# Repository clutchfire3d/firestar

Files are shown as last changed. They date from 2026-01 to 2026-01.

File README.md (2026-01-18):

> [!IMPORTANT]
> **Official STL Files:** The 3D models for the Firestar platform will be available soon on the official **Polarstar Airsoft** website. Stay tuned to our [Discord community](https://discord.gg/8hraAGcFYY) for the official release announcement!

---

# Firestar – Assembly & Printing Manual 🚀
**Created by:** [@ClutchFire3D](https://www.instagram.com/clutchfire3d/)

[**🌐 View Official Website**](https://clutchfire3d.github.io/firestar/)

---

## ⚖️ License & Terms of Use
This project is licensed under **CC BY-NC-ND 4.0**. 
**Commercial use, redistribution, or sale of STL files and printed parts is strictly prohibited.**

---

## 📌 Table of Contents
* [1. Meet Firestar](#1-meet-firestar)
* [2. Recommended Print Settings](#recommended-print-settings)
* [3. Support the Mission](#support-the-mission-keep-the-fire-burning)
* [Step 1: Lower Receiver Preparation](#step-1-lower-receiver-preparation)
* [Step 2: Upper Receiver & Handguard](#step-2-upper-receiver--handguard)
* [Step 3: Trigger Housing & HPA](#step-3-trigger-housing--hpa)
* [Step 4: Stock Adapter](#step-4-stock-adapter)
* [Step 5: Final System Assembly](#step-5-final-system-assembly)
* [Step 6: Stock](#step-6-stock)

---

## 1. Meet Firestar
**Forget Gearboxes. Embrace Innovation.**

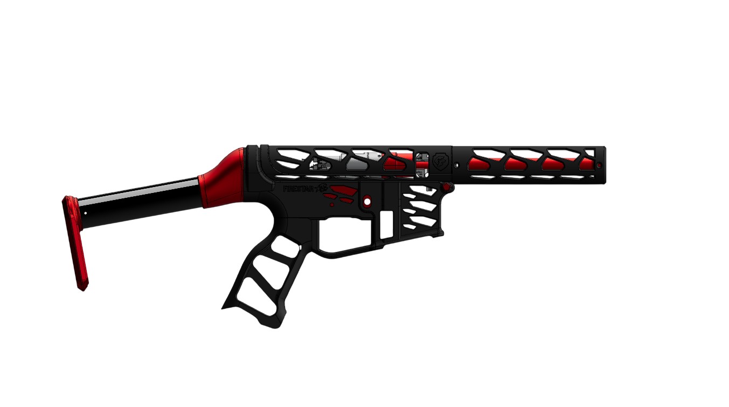
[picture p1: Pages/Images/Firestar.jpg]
Firestar


The Firestar was developed by **ClutchFire3D** leveraging **PolarStar Airsoft** technology. Designed from the ground up to extract maximum performance from the **F2™ and Jack™ HPA engines**, this platform eliminates the limitations of adapted AEG bodies.

---

## 🛠 Recommended Print Settings

To ensure the structural integrity of your Firestar, follow these guidelines:

| Parameter | Recommended Setting |
| :--- | :--- |
| **Material** | **ASA or ABS** (Required for impact resistance and durability) |
| **Wall Line Count** | **4 layers** (Crucial for thread and insert strength) |
| **Infill Density** | **50% or higher** |
| **Support** | Required (Tree supports recommended for cleaner surfaces) |
| **Layer Height** | 0.12mm |

> **⚠️ Warning:** Do not use standard PLA for structural parts, as it may become brittle or warp under heat and mechanical stress.

---

## ❤️ Support the Mission (Keep the Fire Burning)
The **Firestar** is an open-source project. If you find this project valuable, please consider supporting our work.



---

# Step 1: Lower Receiver Preparation

### **Trigger**
Install the trigger blade. Note the specific slot to prevent the selector from over-rotating. Secure with an M3 screw.
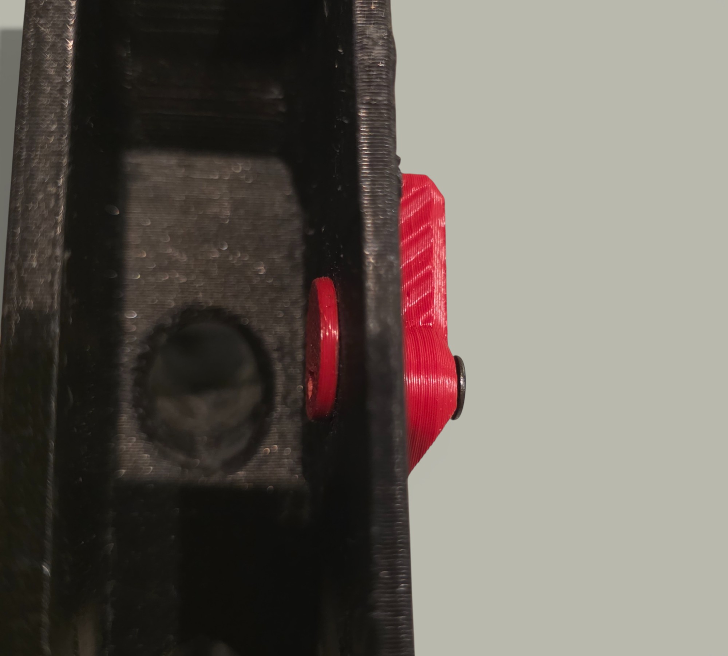
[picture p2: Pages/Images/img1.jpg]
Trigger Install


### **Grip Inserts**
Using a soldering iron, install the M3 brass inserts into the Pistol Grip mounting holes.
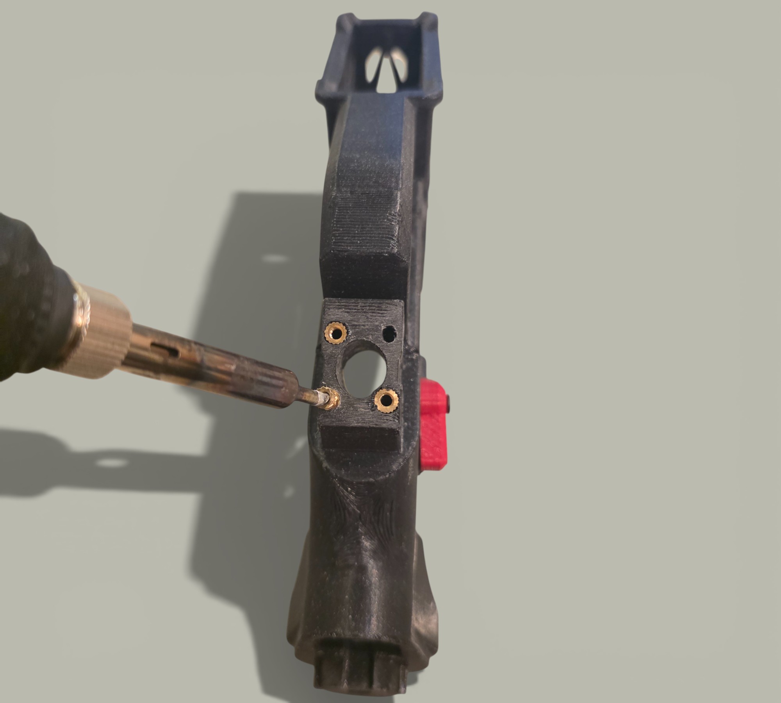
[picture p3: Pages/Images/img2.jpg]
Grip Inserts


### **Grip**
Bolt the Pistol Grip to the body using M3 screws.

| View 1 | View 2 |
| :---: | :---: |
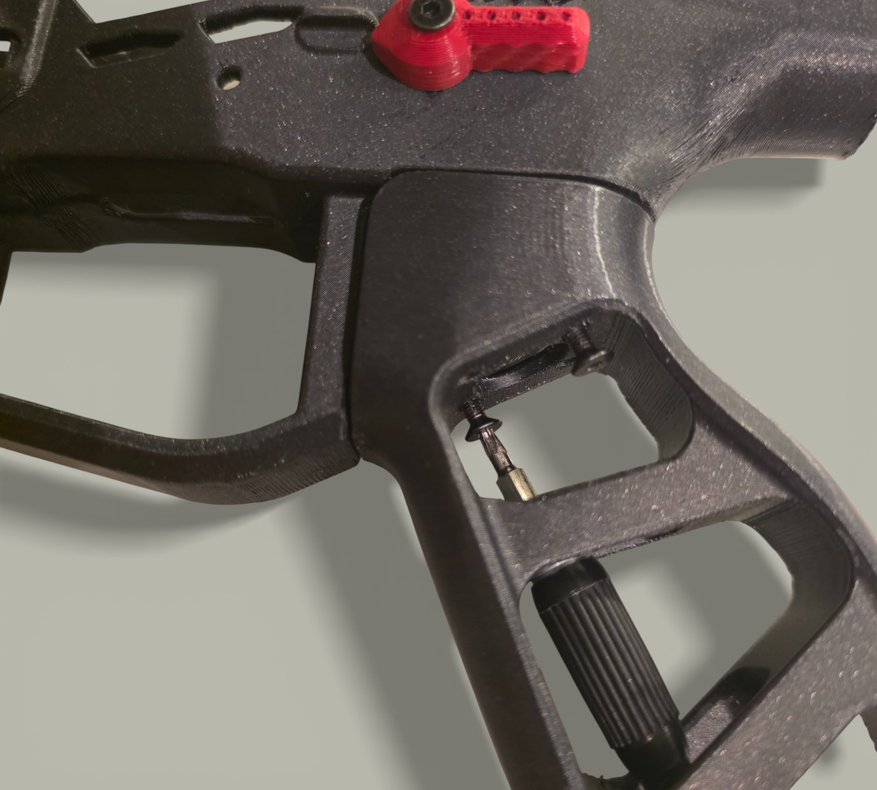
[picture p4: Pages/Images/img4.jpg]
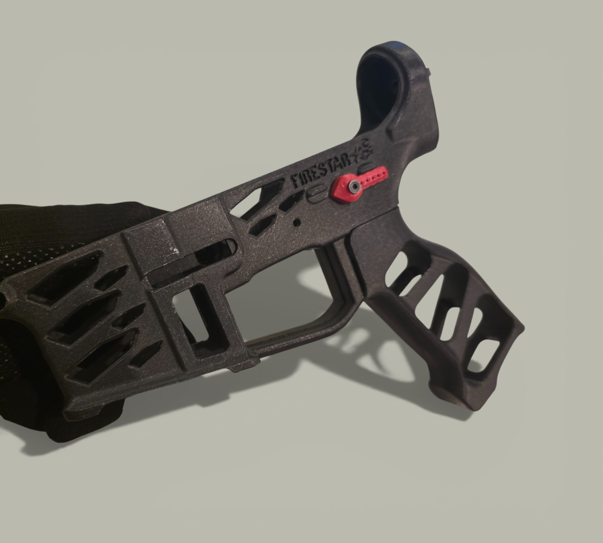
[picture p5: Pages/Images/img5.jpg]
|  |  |

---

# Step 2: Upper Receiver & Handguard

### **Inserts**
Install M3 inserts into both sides of the Upper Receiver and the Outer Barrel.
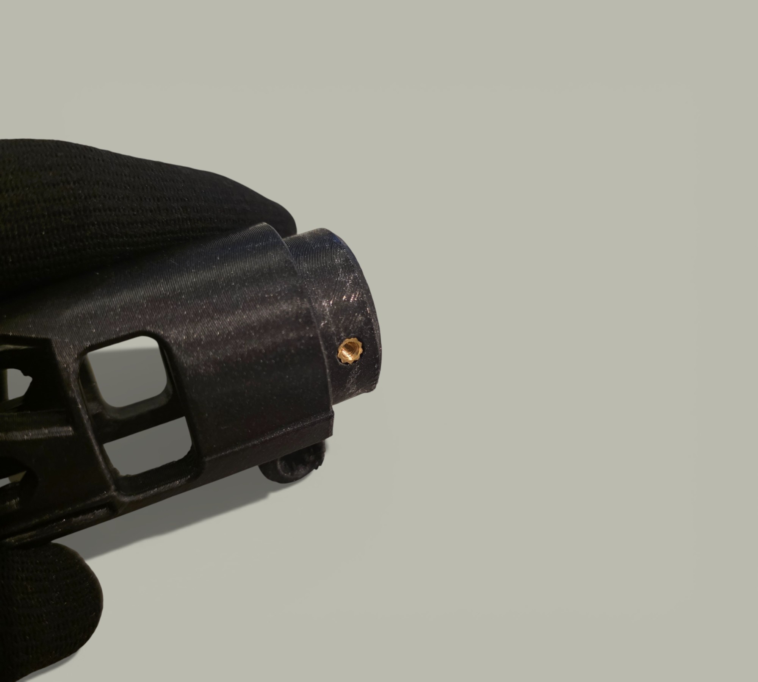
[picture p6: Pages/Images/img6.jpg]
Upper Inserts


### **Muzzle**
Screw the 14mm CCW adapter onto the Outer Barrel tip.
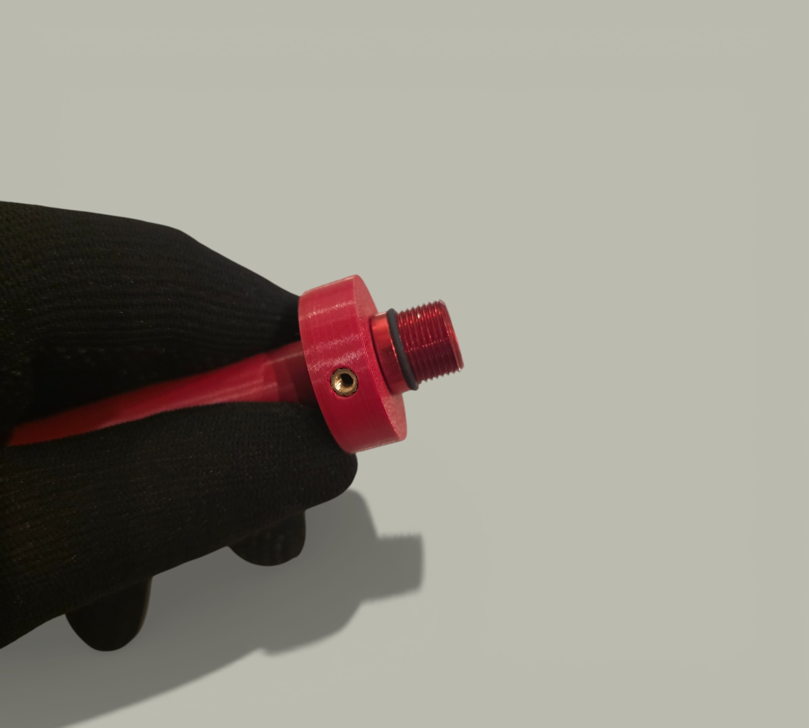
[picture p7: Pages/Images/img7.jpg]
Muzzle Thread


### **Alignment**
Align the Outer Barrel holes with the Handguard. Pay attention to the **chamfered side**.

| Hole Alignment | Screw Tightening |
| :---: | :---: |
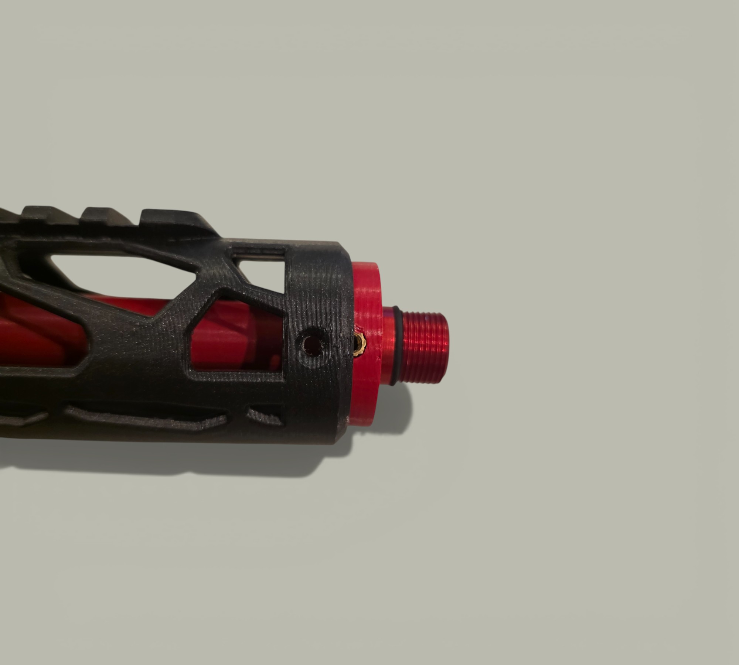
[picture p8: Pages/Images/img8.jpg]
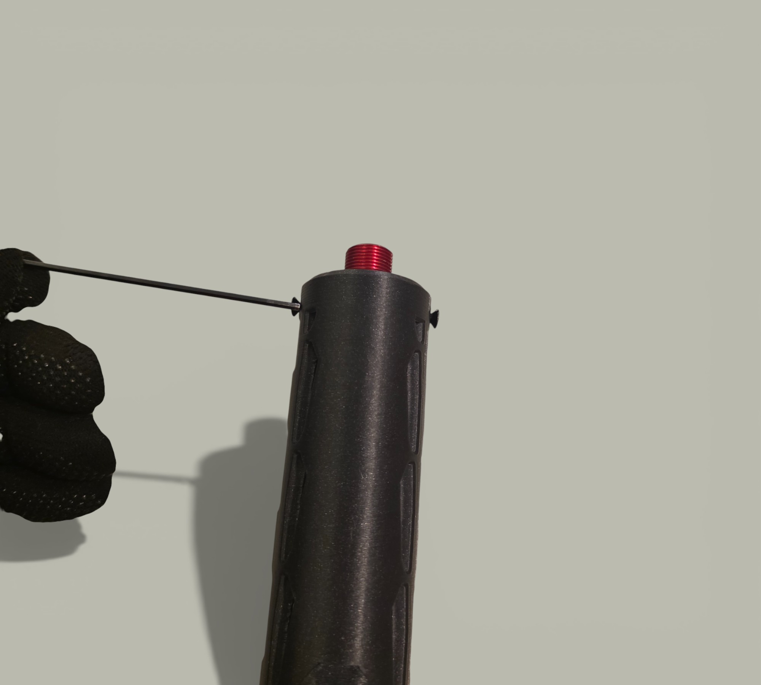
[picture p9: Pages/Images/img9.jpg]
|  |  |

### **Joining**
Slide the Upper into the Handguard and secure both sides with M3 screws.

| Fitting | Hole Alignment |
| :---: | :---: |
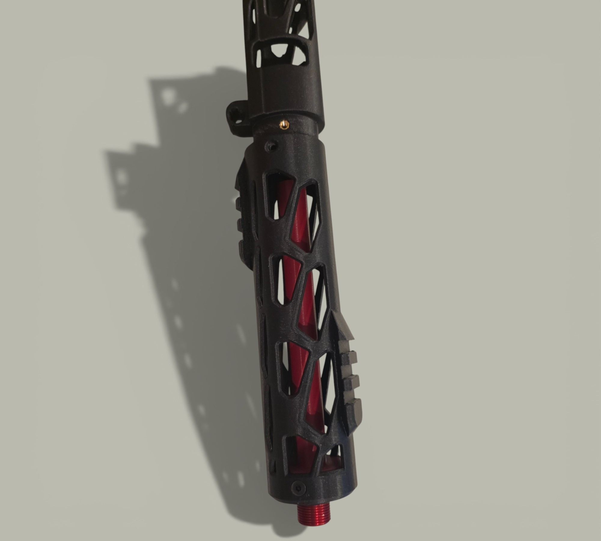
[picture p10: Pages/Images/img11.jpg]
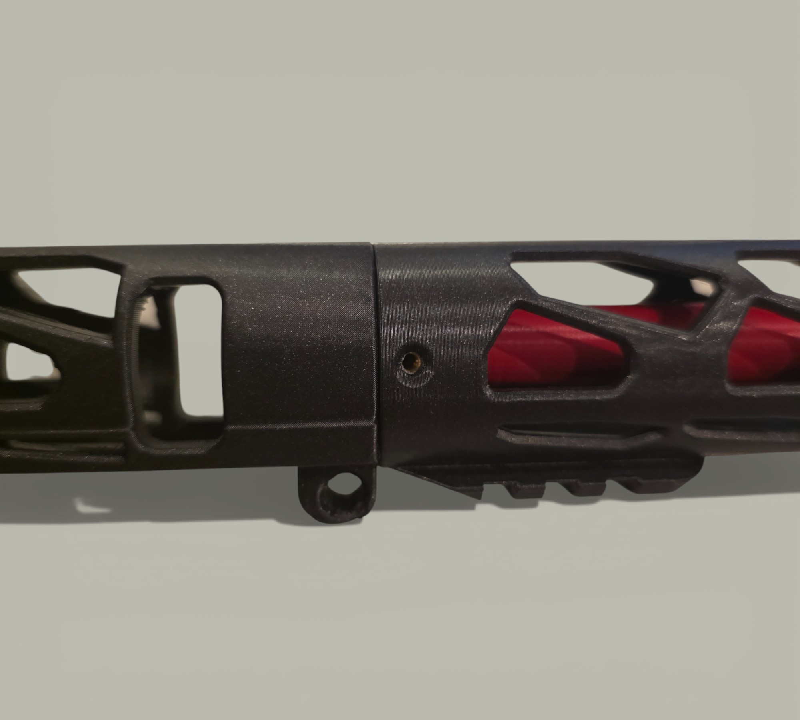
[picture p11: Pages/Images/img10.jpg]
|  |  |

### **Hopup**
Slide the assembled Hopup and inner barrel into the Upper until it hits the internal limiter.

| Polarstar Hopup Thing | Maxx Model View |
| :---: | :---: |
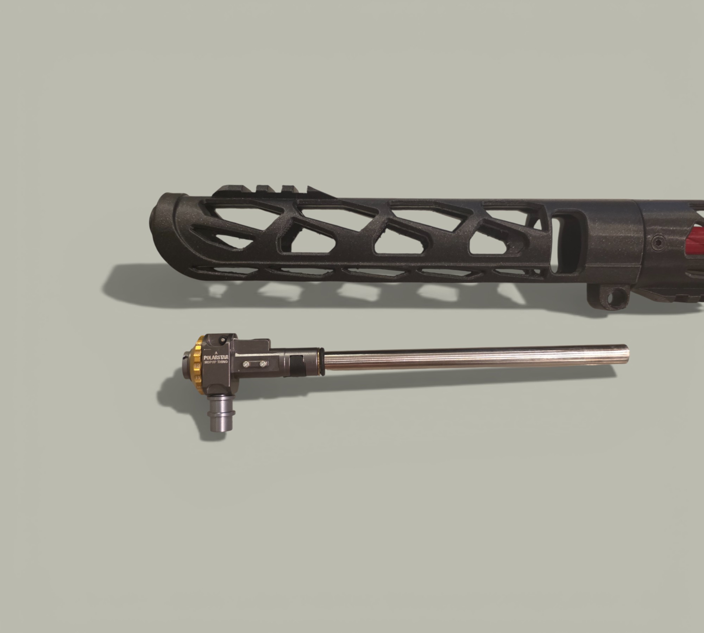
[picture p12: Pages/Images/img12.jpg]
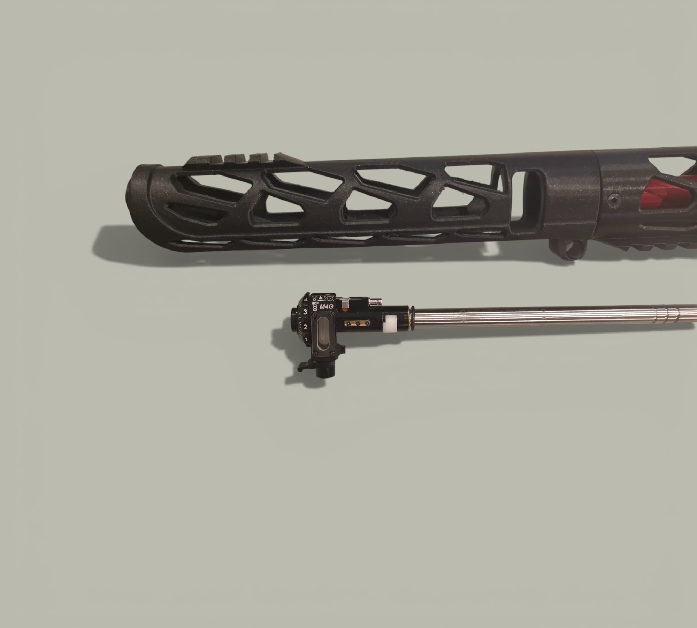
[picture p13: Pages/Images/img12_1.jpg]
|  |  |

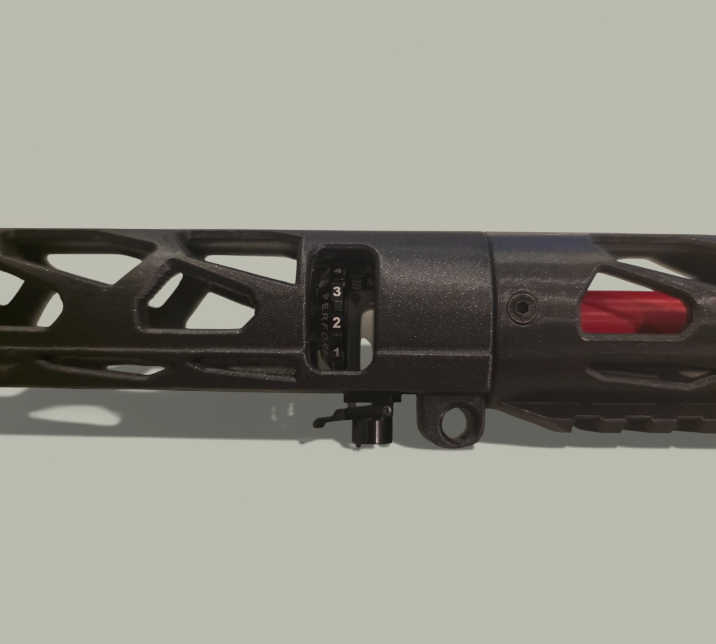
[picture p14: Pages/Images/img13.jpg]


---

# Step 3: Trigger Housing & HPA

### **Trigger Board**
Fix the F2 trigger board to the left side of the Housing using the original small screw.

| Trigger Housing L | Board |
| :---: | :---: |
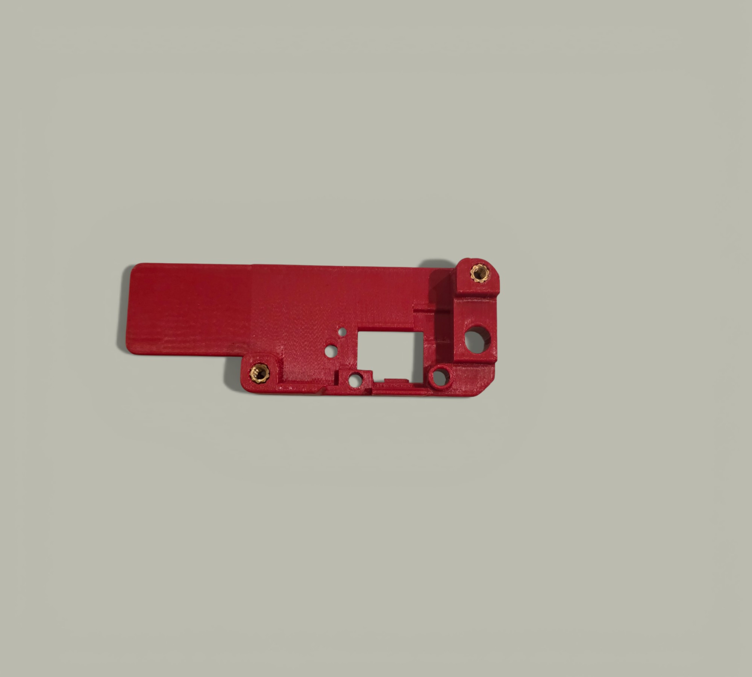
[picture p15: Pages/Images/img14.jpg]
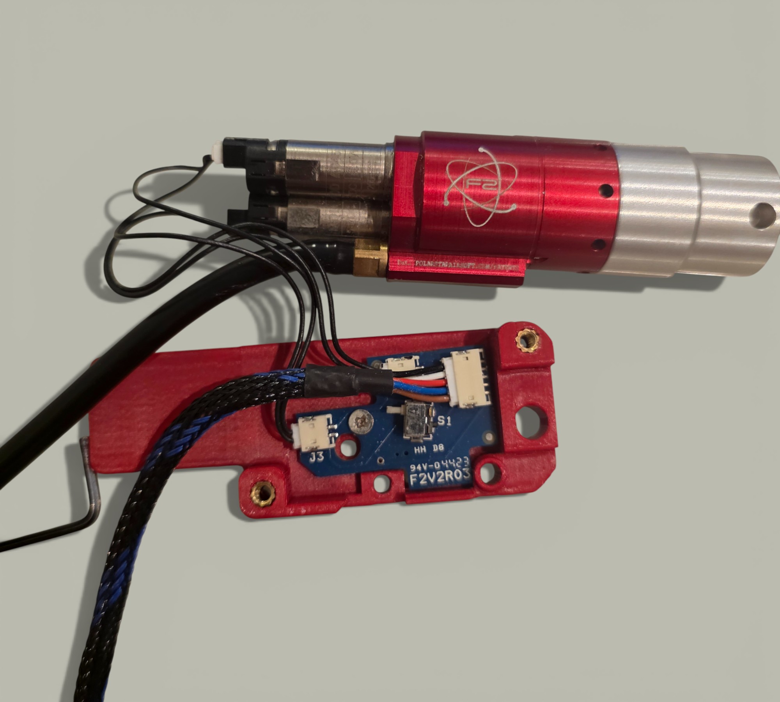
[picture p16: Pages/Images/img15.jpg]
|  |  |

### **Assembly**
Place the trigger blade in its housing, close it with the right side, and secure with M3 screws.

| Trigger Blade | Housing Closing |
| :---: | :---: |
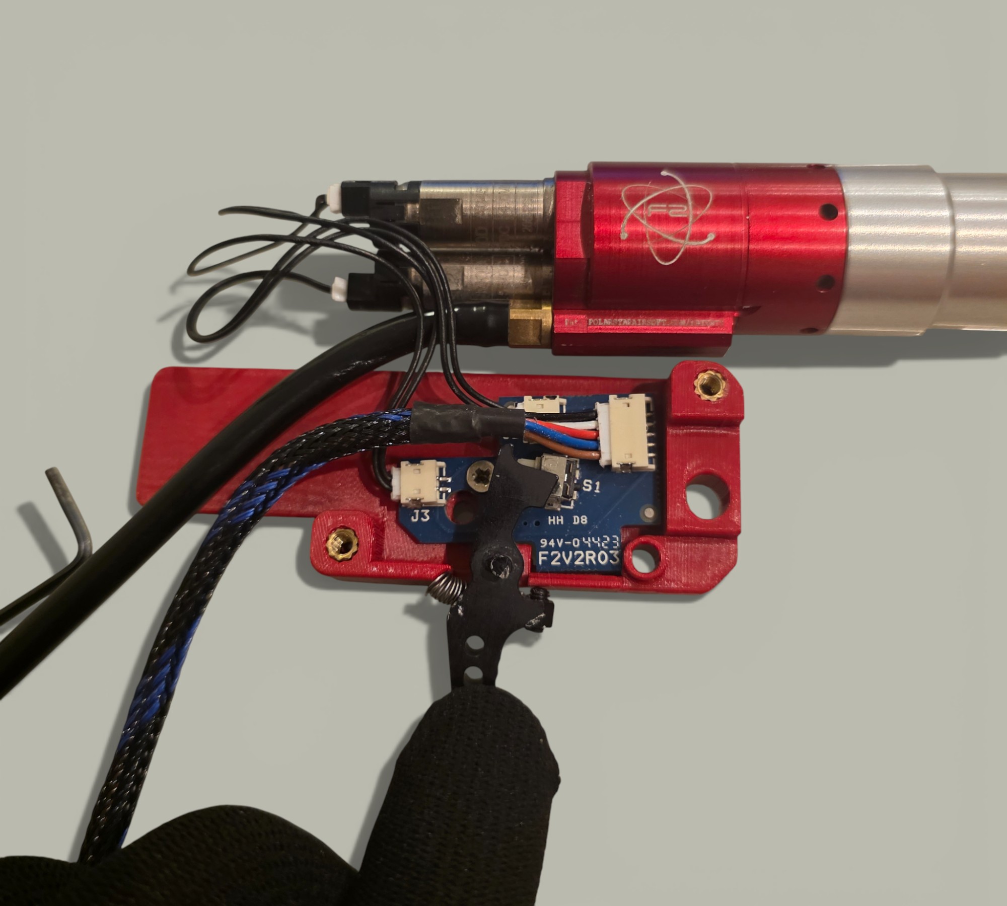
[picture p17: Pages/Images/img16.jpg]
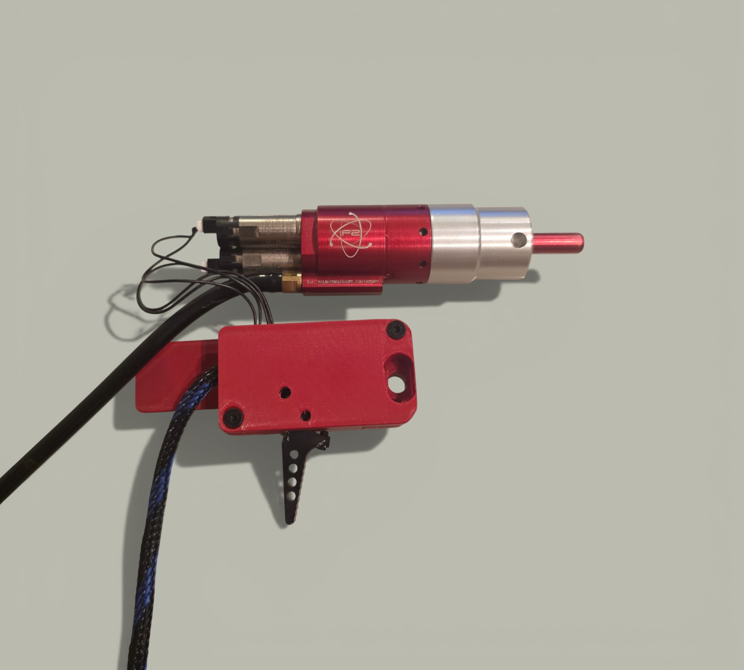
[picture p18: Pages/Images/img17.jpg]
|  |  |

### **Selector**
Snap the Selector Plate into place.
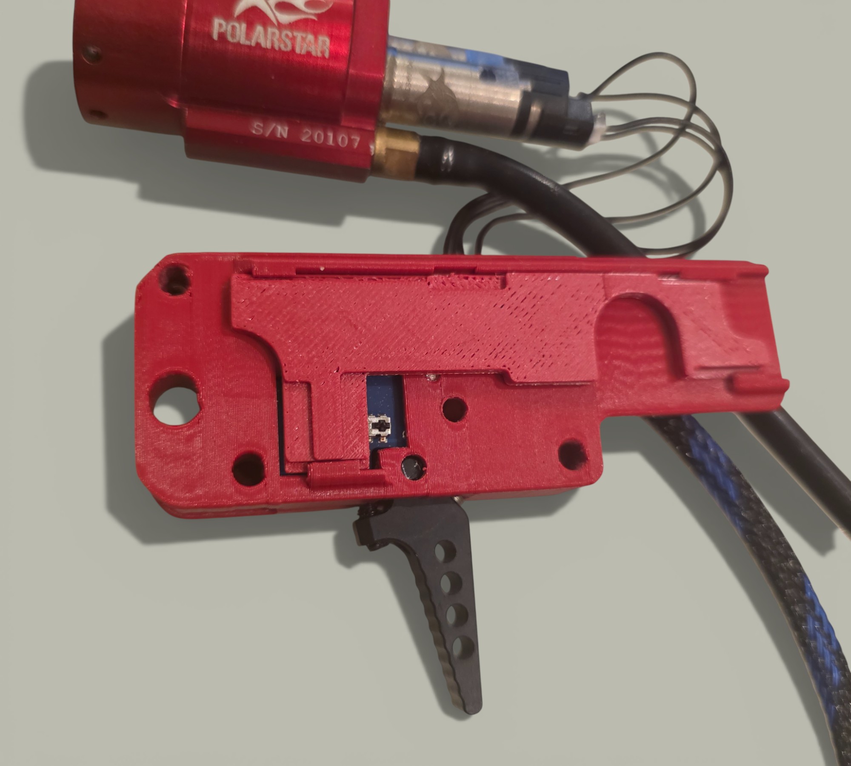
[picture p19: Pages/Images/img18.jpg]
Selector Plate


---

# Step 4: Stock Adapter

### **Nut Setup**
Place the M5 nut inside the specific slot within the Lower Receiver.
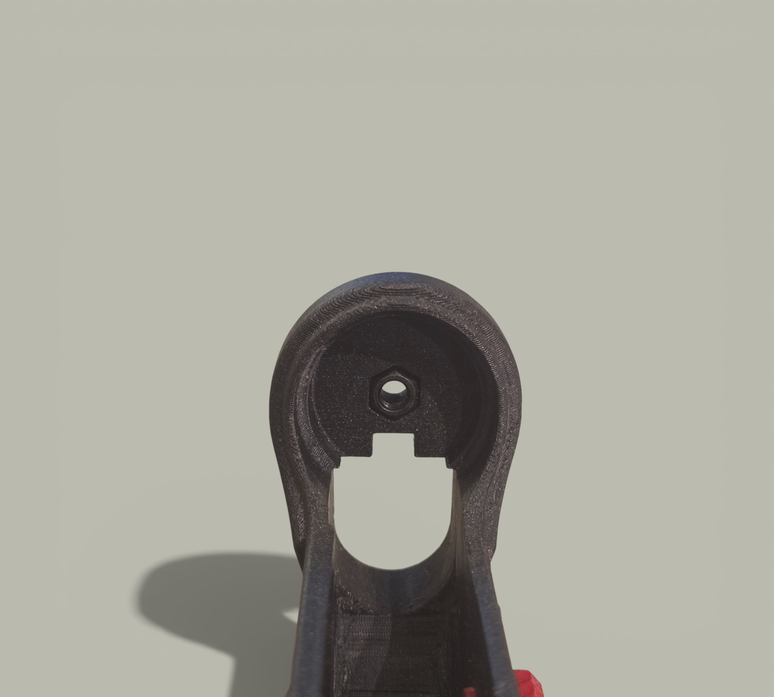
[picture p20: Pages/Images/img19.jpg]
M5 Nut


### **Fixation**
Install the Stock Adapter before the HPA system and secure it with the M5 screw.
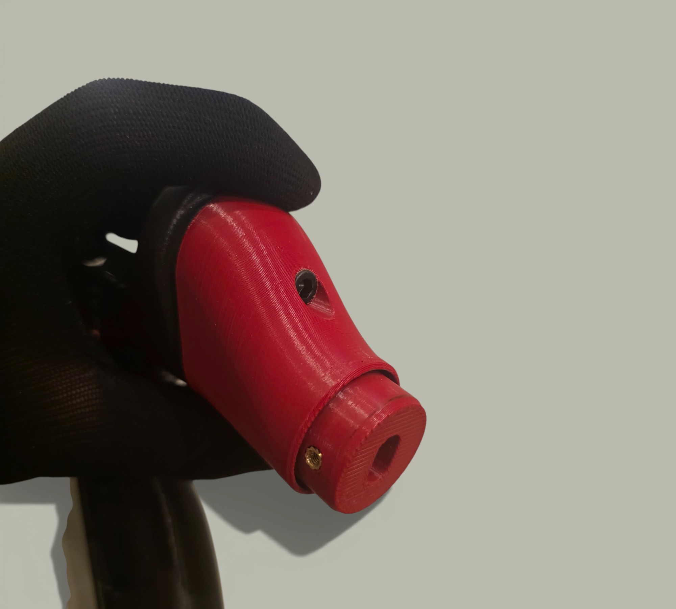
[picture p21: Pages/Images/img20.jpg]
Adapter Mount


---

# Step 5: Final System Assembly

### **Wiring**
Route the FCU wires through the Stock Adapter and the air line through the Pistol Grip hole.
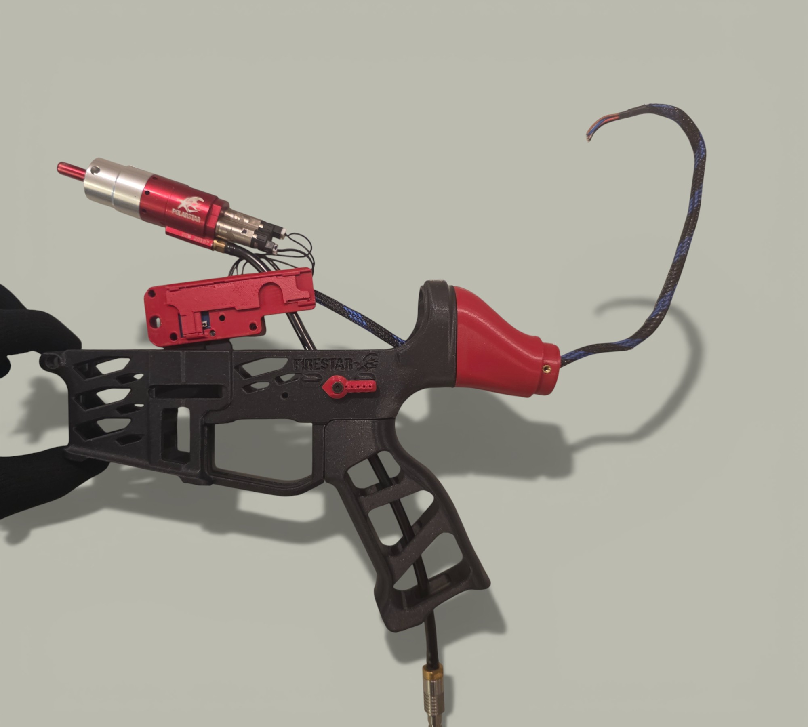
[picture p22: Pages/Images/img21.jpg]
Wiring Route


### **Trigger Box**
Slide the Trigger Housing into the Lower and lock it with the **Lower Pin**.
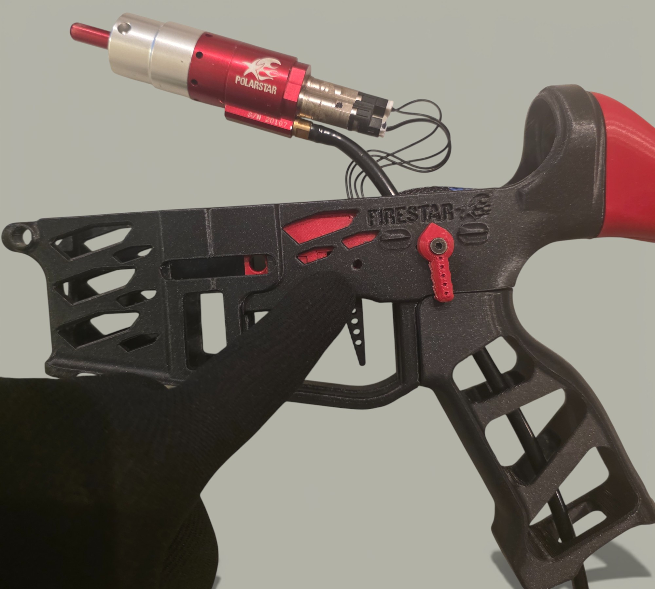
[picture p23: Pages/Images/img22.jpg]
Trigger Box Install


### **Engine**
Slide the F2 engine into the Upper until it seats into the Hopup.
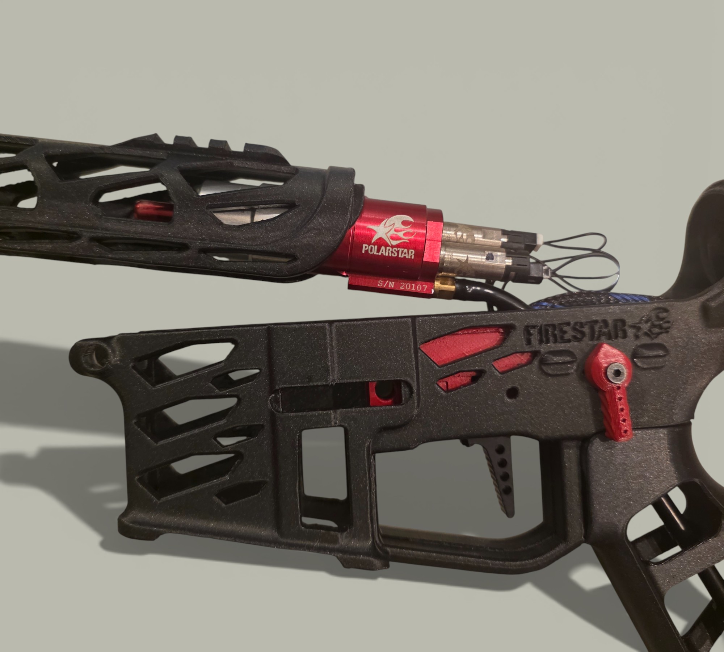
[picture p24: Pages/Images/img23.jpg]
Engine Slide


### **Lock**
Install the **F2 Lock** to prevent the engine from moving during shots.
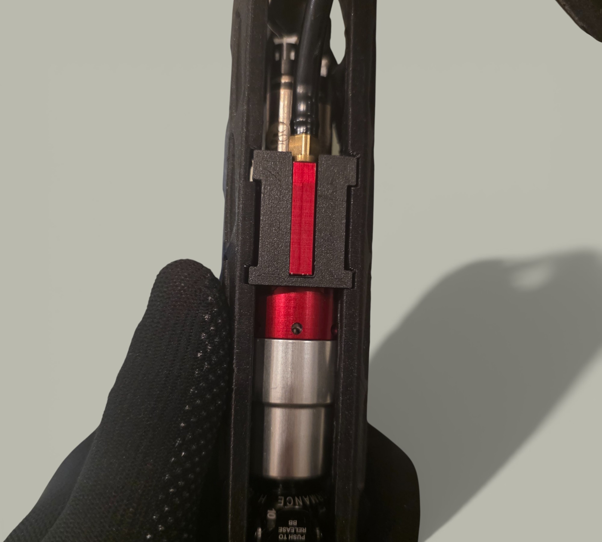
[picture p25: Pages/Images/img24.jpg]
Engine Lock


### **Closing**
Join the Upper and Lower receivers and lock with the front pin.
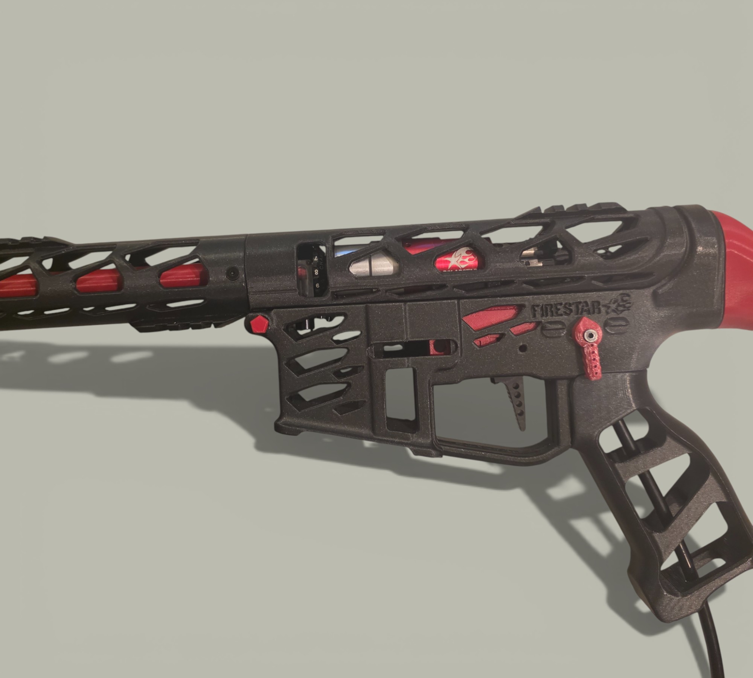
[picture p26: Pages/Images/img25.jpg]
Body Pins


### **Mag Release**
Install the printed (or aftermarket M4) Mag Release with the spring. Ensure smooth movement.

---

# Step 6: Stock

### **Carbon Tube**
Cut the carbon fiber tube to length and drill the mounting holes.

### **Stock**
Install M3 inserts into the printed Stock part and bolt it to the tube.
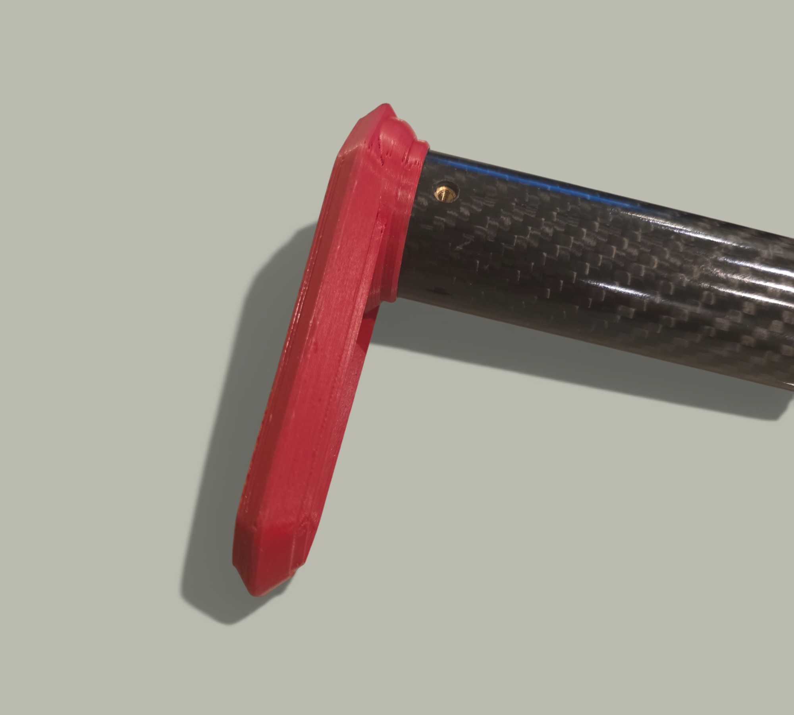
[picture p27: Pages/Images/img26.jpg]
Stock Mount


### **Finalize**
Connect the FCU and battery, tuck the wires into the tube, and slide it onto the Adapter.

| Connection | Stock Fitting |
| :---: | :---: |
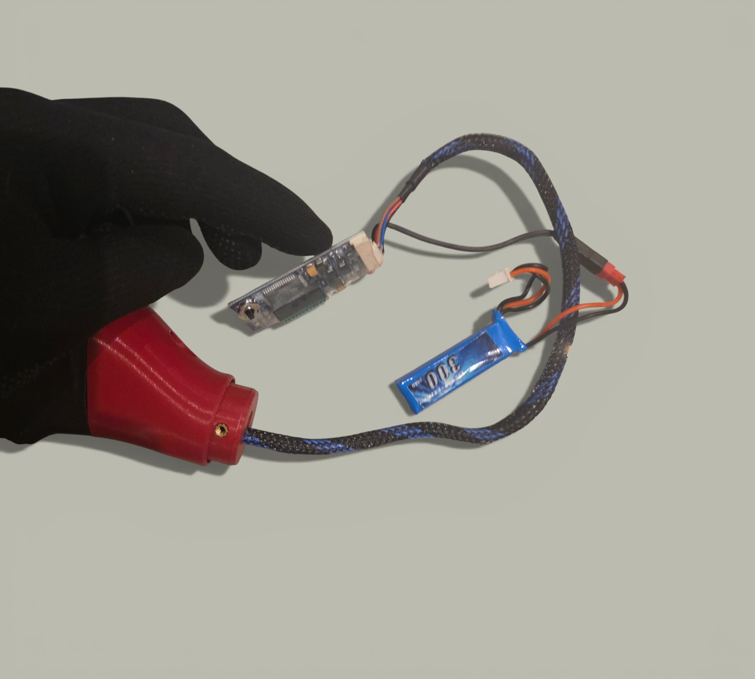
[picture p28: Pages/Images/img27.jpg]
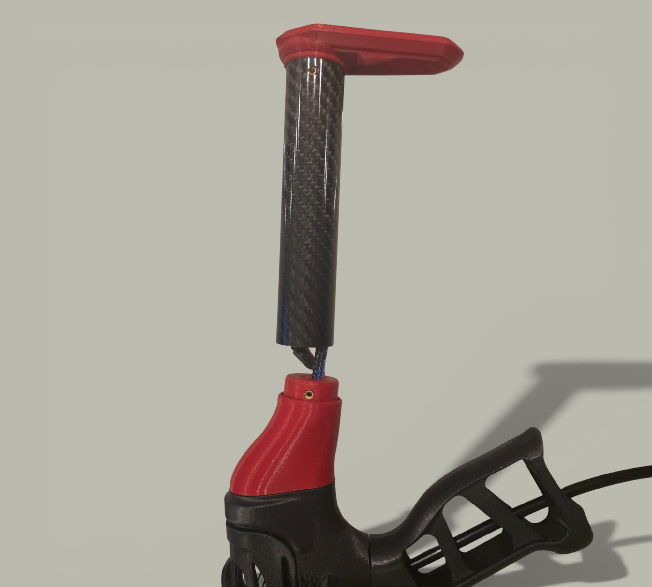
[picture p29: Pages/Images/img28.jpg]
|  |  |

---

## 🔥 Build Complete!
Share your Firestar build on Instagram and tag **@ClutchFire3D**.

[Join our Discord](https://discord.gg/8hraAGcFYY) | [Support the Project](https://clutchfire.com)

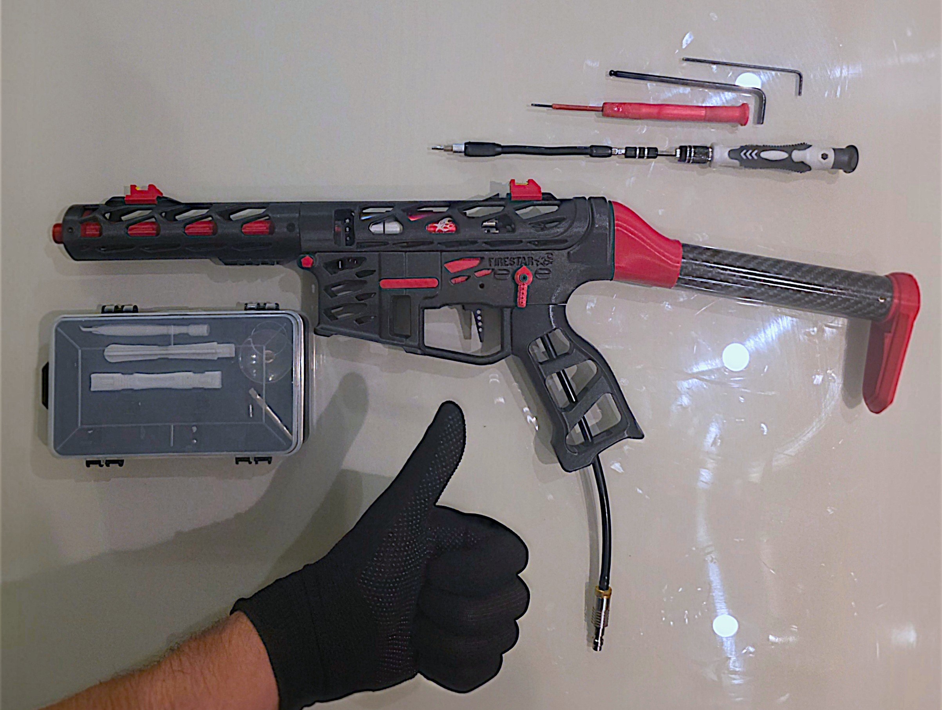
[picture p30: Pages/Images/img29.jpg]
Final Build


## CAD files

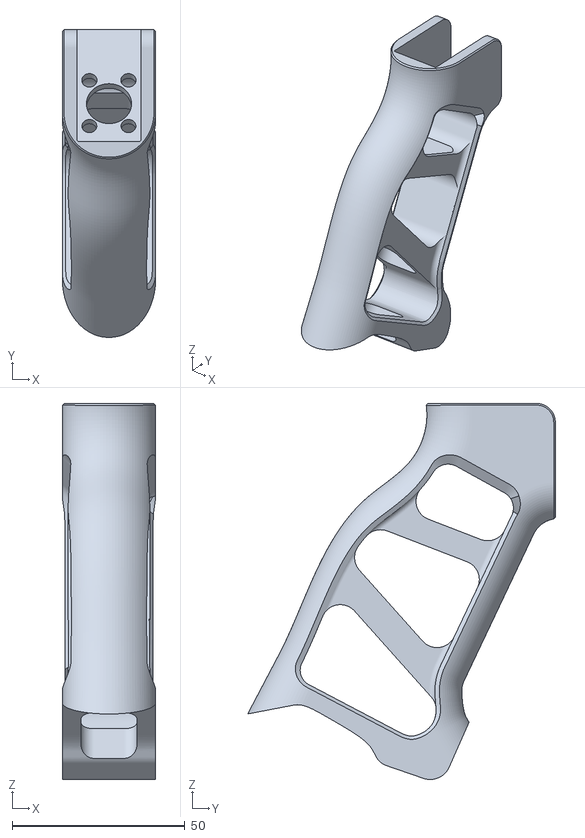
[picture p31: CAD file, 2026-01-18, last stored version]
STLs/PistolGrip/PistolGrio_Firestar.stl
27.0 x 89.2 x 109.0

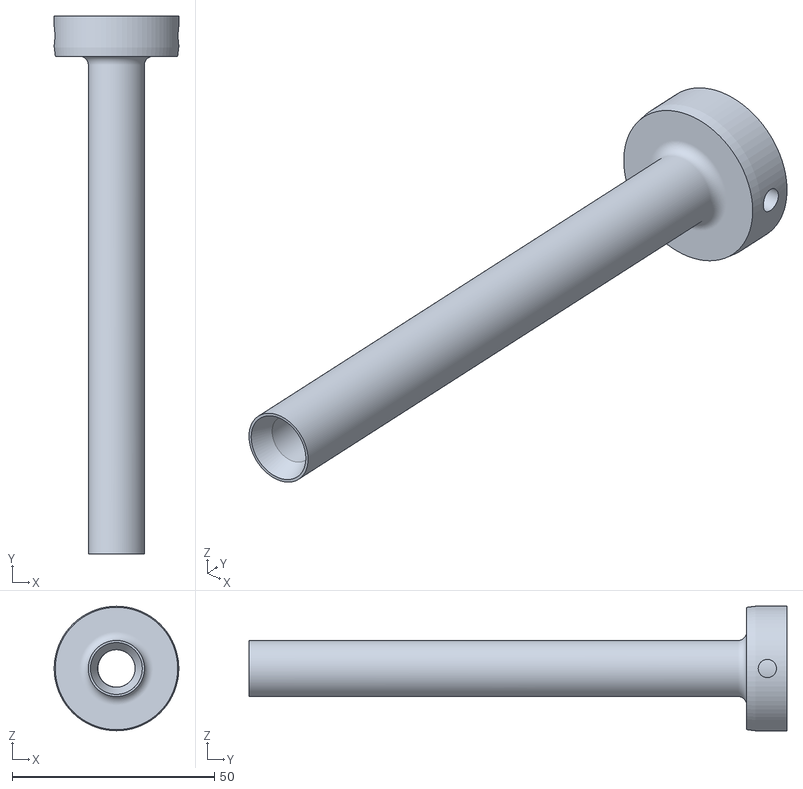
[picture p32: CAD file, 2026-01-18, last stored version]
STLs/Receivers/OuterBarrel_Firestar.stl
30.8 x 133.0 x 30.8

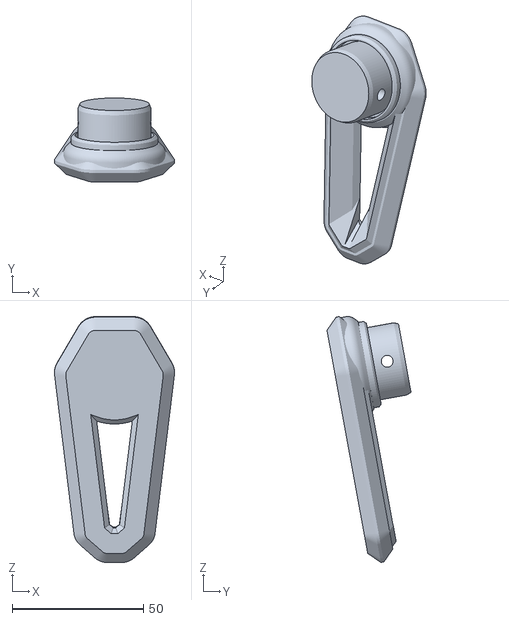
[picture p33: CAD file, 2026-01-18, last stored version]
STLs/Stock/Stock_Firestar.stl
45.8 x 32.0 x 93.8

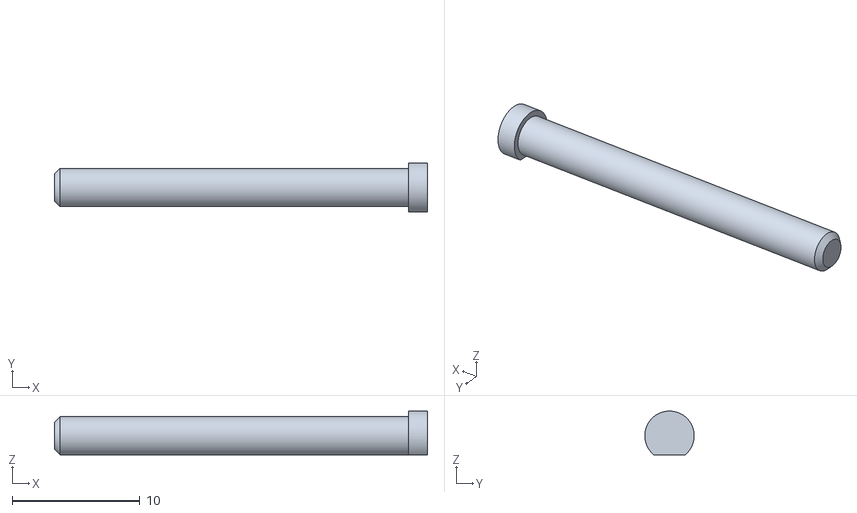
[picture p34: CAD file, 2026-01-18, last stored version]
STLs/TriggerHousing/TriggerHousing_Pin_Firestar.stl
29.2 x 3.87 x 3.43

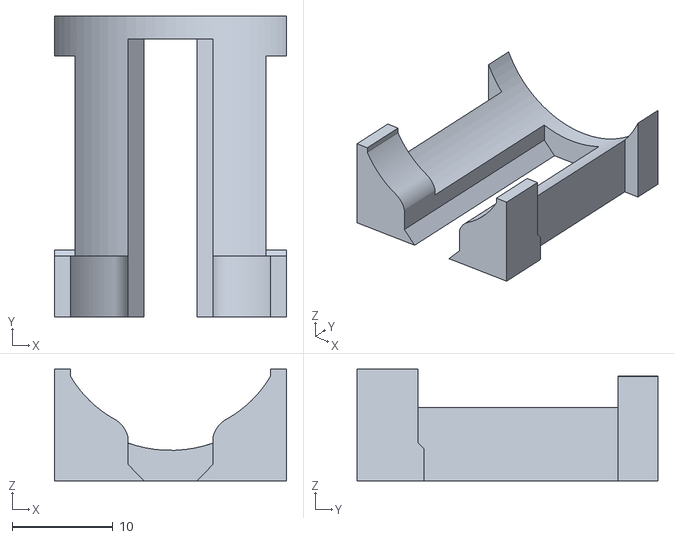
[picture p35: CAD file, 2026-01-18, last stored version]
STLs/Receivers/F2Lock_Firestar.stl
23.1 x 30.0 x 11.1

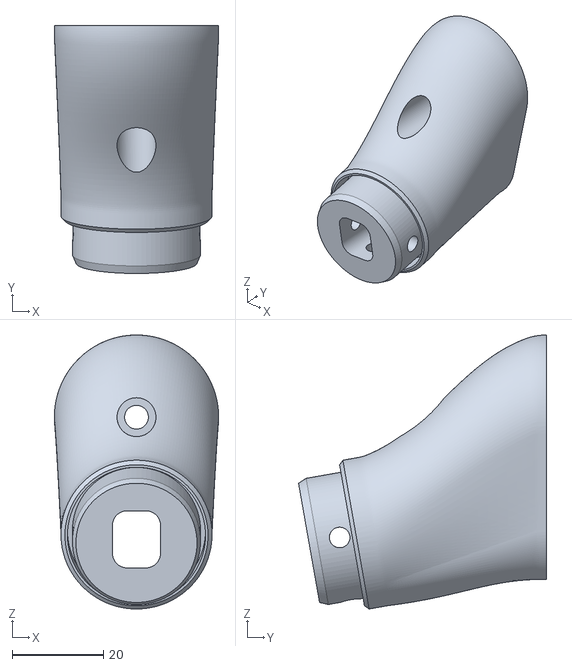
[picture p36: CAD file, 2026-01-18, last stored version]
STLs/Stock/StockAdapter_Firestar.stl
36.0 x 54.3 x 60.0

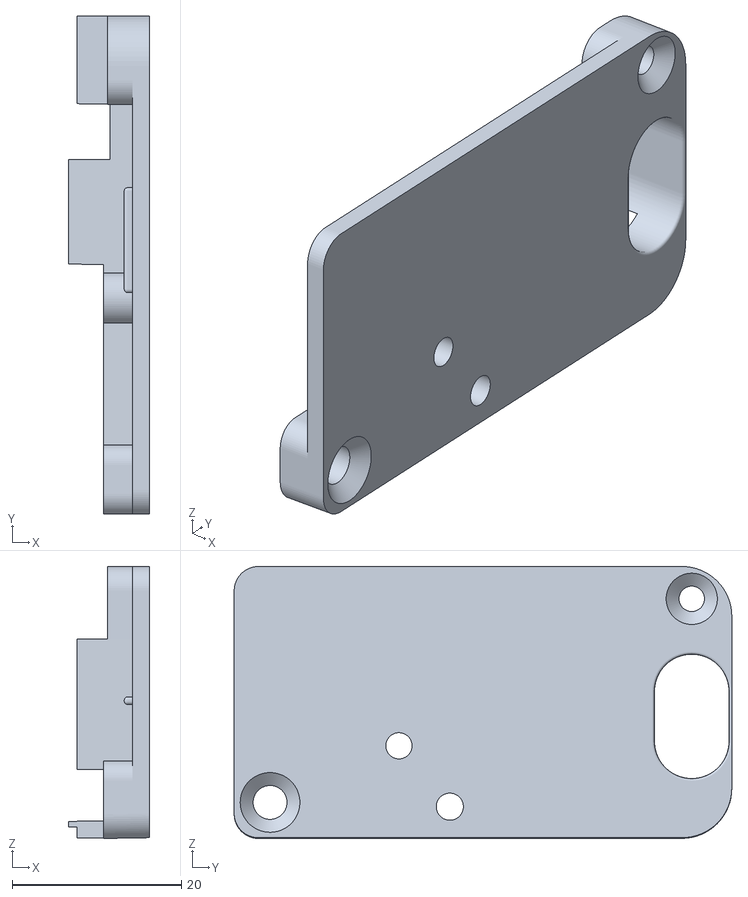
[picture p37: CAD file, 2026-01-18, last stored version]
STLs/TriggerHousing/TriggerHousing_R_Firestar.stl
9.60 x 58.8 x 32.1

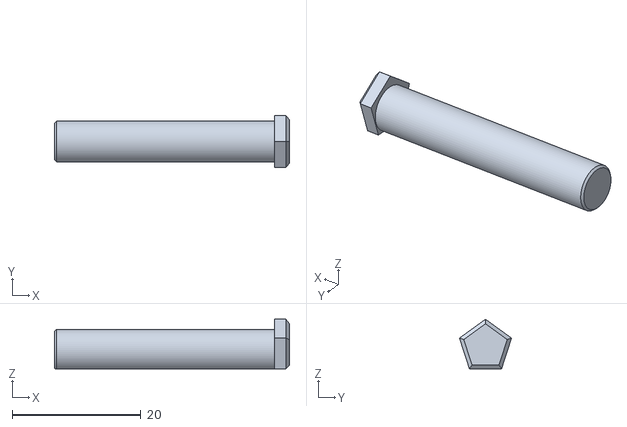
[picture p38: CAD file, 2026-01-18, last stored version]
STLs/Receivers/LowerPin_Firestar.stl
36.5 x 8.10 x 7.70

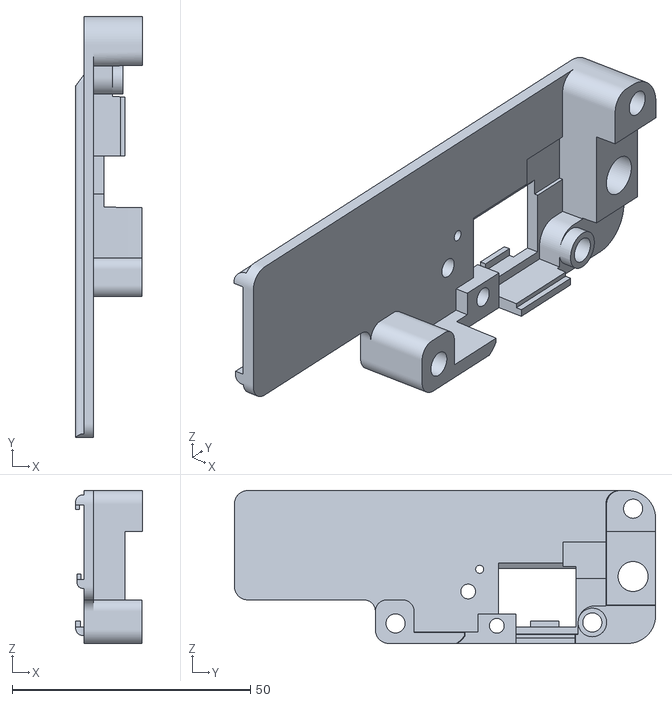
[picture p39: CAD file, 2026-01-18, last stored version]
STLs/TriggerHousing/TriggerHousing_L_Firestar.stl
14.0 x 88.3 x 32.1

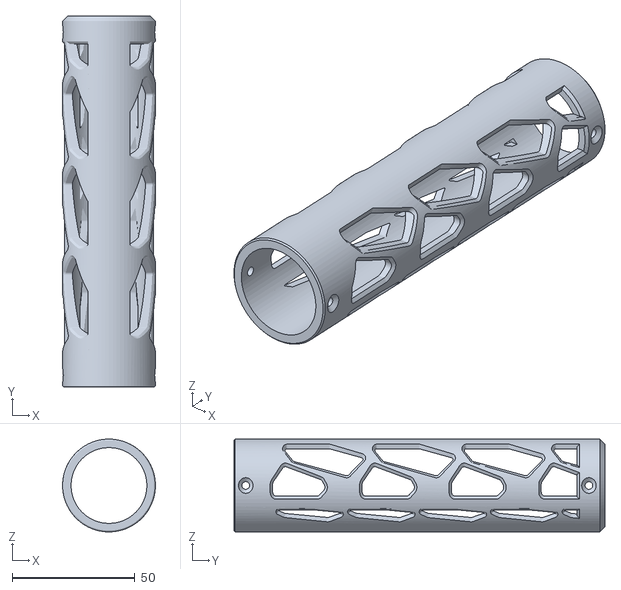
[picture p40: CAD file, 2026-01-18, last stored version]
STLs/Receivers/HandGuard_Firestar.stl
37.8 x 151.1 x 37.8

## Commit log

2026-01-17 feat: complete assembly manual + basic STLs pack
    [F2Lock_Firestar.stl, HandGuard_Firestar.stl, LowerPin_Firestar.stl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]
2026-01-17 git commit -m "docs: add english manual and CC license, assets: add STL folder"
2026-01-18 add english manual and CC license, assets: add STL folder
2026-01-18 HEADME updates
    [F2Lock_Firestar.stl, HandGuard_Firestar.stl, LowerPin_Firestar.stl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]
